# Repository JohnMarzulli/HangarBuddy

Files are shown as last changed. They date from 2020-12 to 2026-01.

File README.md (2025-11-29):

# HangarBuddy

This code controls an AC/DC relay attached to a Raspberry Pi
with a heater plugged in.

It is designed to have a radio of some sort attached that recieves commands and sends responses or alerts.

## Features

1. Extensibility
1. Hangar environment monitoring
1. Continuous vaporized gas monitoring and alerting
1. Status display
1. Rich text commands and responses

## Acknowledgements

This project started as a fork of piWarmer by Maria DeGrazia.
[https://github.com/mdegrazia/piWarmer](https://github.com/mdegrazia/piWarmer)

I want to extend my many thanks to Maria for starting such an amazing project!

The light sensor code is derived from Ada Fruit's samples.
The temperature code is heavily based on the SunFounder sample code.
The ANALOG gas sensor code is also derived from SunFounder sample code.

## Disclaimer

**HangarBuddy is to be used at your own risk.** It is an
experimental device.

## Commands

The commands are not case sensitive.

| SMS Message | Action |
|---|---|
| ON | Turn the Relay/Heater on |
| OFF | Turn the Relay/Heater off |
| STATUS | Return status of the Relay/Heater (on or off) |
| HELP | Return the list of commands. |
| SHUTDOWN | Shutdown the Pi |

## Setup

You will need to modify the HangarBuddy.config file to match your installation.
This file includes a list of phone numbers that are authorized to issue
commands. The file also includes a phone number that any alerts will be sent to.

The basic install process (from scratch):

- Image a micro-SD card using the Raspberry Pi Imager. Keep the user name as `Pi`. You may optionally setup your wifi network name and password.
- In the Pi user directory, make a directory name `src`, navigate into it, then clone the Hangar Buddy repo
- In `/home/user/pi/src/HangarBuddy`, you will need to run and activate a "Python Virtual Environment"
- `python -m venv venv`
- `source ./venv/bin/activate`
- `pip install meshtastic`
- IF you are using an older version of Raspberry Pi OS and NOT using a PI 5: `pip install RPi.GPIO`
- For Pi5 & Bookworm: ``
- `pip install smbus`
- `pip install pyserial`

You will also need to enable some system settings:

- `sudo raspi-config`
- Enable I2C, SPI, 1 Wire Serial, and the Serial interface

## Wiring

**Note**: There are two pin numbering conventions for the Raspberry Pi: Pi numbering and board numbering.

For instance GPIO25 is also known as physical pin 22. It is located on the edge of the PCB, in the middle of the column.

[Raspberry Pi Pin Reference](https://learn.sparkfun.com/tutorials/raspberry-gpio/gpio-pinout)
[Another Pi Pin Reference](https://forum.arduino.cc/t/raspberry-pi-gpio-pins/518283)

### Full Wiring Diagram

Physical Pins 1 and 2 are at the edge of the board with the Micro-SD Card

| Device Connection | Device Connection | Device Connection | Physical Pin / Pi Pin Name | Physical Pin / Pi Pin Name | Device Connection |
|---|---|---|---|---|---|
| | TSL2561 VCC (white)  | | Pin 1 — 3V3 Power | Pin 2 — 5V Power | Display VCC (red) |
| | TSL2561 SDA (green)  | Display SDA (green)  | Pin 3 — GPIO2 / SDA1 | Pin 4 — 5V Power | |
| | TSL2561 SCL (yellow) | Display SCL (yellow) | Pin 5 — GPIO3 / SCL1 | Pin 6 — GND | Display Ground (black) |
| | | DHT22 OUT (gray) | Pin 7 — GPIO4 | Pin 8 — GPIO14 / UART TX | |
| | TSL2561 GND (black)  | | Pin 9 — GND | Pin 10 — GPIO15 / UART RX  | |
| | | | Pin 11 — GPIO17 | Pin 12 — GPIO18 | |
| | | | Pin 13 — GPIO27 | Pin 14 — GND | |
| | | | Pin 15 — GPIO22 | Pin 16 — GPIO23 | |
| MQ2 VCC (white) | | DHT22 VCC (white) | Pin 17 — 3V3 Power | Pin 18 — GPIO24 | |
| | | | Pin 19 — GPIO10 / SPI MOSI | Pin 20 — GND | Relay GND (black) |
| | | | Pin 21 — GPIO9 / SPI MISO  | Pin 22 — GPIO25 | Relay + (blue) |
| | | | Pin 23 — GPIO11 / SPI SCLK | Pin 24 — GPIO8 / SPI CE0 | |
| | | DHT22 GND (black) | Pin 25 — GND | Pin 26 — GPIO7 / SPI CE1 | |
| | | | Pin 27 — ID_SD | Pin 28 — ID_SC | |
| | | | Pin 29 — GPIO5 | Pin 30 — GND | |
| | | | Pin 31 — GPIO6 | Pin 32 — GPIO12 | |
| | | | Pin 33 — GPIO13 | Pin 34 — GND | |
| | | | Pin 35 — GPIO19 | Pin 36 — GPIO16 | |
| MQ2 DO (gray) | | | Pin 37 — GPIO26 | Pin 38 — GPIO20 | |
| MQ2 GND (black) | | | Pin 39 — GND | Pin 40 — GPIO21 | |

Physical pins 39 and 40 are next to the ethernet or USB housing (model dependant)

### Relay

| Wire Color | RPi Pin | Relay Pin |
|---|---|---|
| Red | GPIO25/22 | "+" |
| Black | GND | "-" |

#### Meshtastic & Meshcore Devices

**NOTE** : Make sure the antenna is attached before powering on.
**NOTE** : The Raspberry Pi 4C seems VERY picky about the USB cable used to connect a Heltec device. Try multiple cables.

| Wire Color | RPi Pin | Relay Pin |
|---|---|---|
| Black | USB-A | USB-C |

### MQ-2 Gas Sensor

The labels for the board are hard to read. The Digital output pin is next to the VCC pin. All three pins will be in a row.

| Wire Color | RPi Pin | MQ2 Pin |
|---|---|---|
| white | 3V | Vcc |
| Black | GND | GND |
| Gray | GP26 / 31 | DO |

### Temp Sensor

Note that the temperature sensor probably was delivered with a pig-tail harness.

| Wire Color | RPi Pin | DS18B20 Pin |
|---|---|---|
| Black | GND | GND |
| Red | +5V | VCC |
| Yellow | GPIO 04 / 7 | IN |

## Light Sensor

**NOTE**: If you have the IO hat installed on the Pi, then you
can use the duplicate SDA/SLC connectors on the set screw
side **AND** the connector pin side.

| Wire Color | RPi Pin | TSL2591 Pin |
|---|---|---|
| Red | +3VC | VCC |
| Black | GND | GND |
| White | SDA/03  | SDA |
| Gray | SLC/05  | SLC |

### Status Display

#### Additional Work

You may need to make to "Y" pig tails to support the additional
i2c device. These would split the SDAI and SCLI lines.

**NOTE**: If you do not intend on using both the light sensor AND the display, then you will not not to make pigtails.

| Wire Color | RPi Pin | SF1602 Pin |
|---|---|---|
| Red | +5V | VCC |
| Black | GND | GND |
| White | SDA/GPIO2/Phys 3 | SDA |
| Gray | SCL/GPIO3/Phys 5 | SCL |

## Additional Links And Setup Notes

### Enable Analog-To-Digital Converter For The MQ-2 Gas Sensor

To do this, you need to enable I2C and 1-Wire using `raspi-config`

```bash
sudo raspi-config
```

- Select Option 5 `Interfacing Options`

- Select Option `P5 I2C` and enable
- Select Option `P7 1-Wire` and enable
- Save changes, exit `raspi-config` and reboot your Raspberry Pi

#### Enable the temperature sensor

Modprobe two modules for the temperature sensor:

```bash
sudo modprobe w1-gpio
sudo modprobe w1-therm
```

## Pairing Meshcore

You will want two meshcore devices.

I suggest using the following 3D printed cases: [Heltec V4 Case](https://www.printables.com/model/1460642-3d-printed-enclosure-for-heltec-v4gps)

The first will be a "Companion USB" that will attach to the Hangar Buddy.

The second will probably be a "Companion Bluetooth" that will be conncted to your phone.

The flasher can be obtained at [flasher.meshcore.co.uk](https://flasher.meshcore.co.uk/)

Make sure both devices are running the same version number of the Meshcore firmware.

You will need to pair the two devices using "adverts". Exact instructions can be found on the Meshcore site.

1. Use [Meshcore App](https://meshcore.liamcottle.net/) to:
    1. Name the device
    1. Set region and bandwidth
    1. Send an advert from the device that will be used for the Hangar Buddy.
1. Use the Mesh Core app on your phone to:
    1. Connect by Bluetooth
    2. Name the device
    3. Send back an advert.
1. Use the Web App to send a direct message from the Hangar Buddy device to your phone paired device.

If you are unable to send messages between the devices, consult the Meshcore documentation, Reddit, or others.

## Materials List

All the parts listed are from Amazon

### Absolutely Required

This assumes you are building "from scratch" and need to buy a Raspberry Pi and
associate parts. I have picked a version of the Pi Zero that has Wireless, which
is good if you want to pull the code down directly onto the Pi

Any version of the Raspberry Pi should work for this project as long as it has
GPIO pins, and an I2C bus.

The LiPo battery is absolutely required and used directly by the GSM board.

A MicroUSB to USB adapter is required for the modem to connect into the Pi
Zero's ****only**** USB port.

- [ ] [Raspberry Pi W, case, and IO pins](https://www.amazon.com/Raspberry-Starter-Power-Supply-Premium/dp/B0748MBFTS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)
- [ ] [Adafruit GSM board, SMA edition](https://www.amazon.com/gp/product/B011P07916/ref=oh_aui_detailpage_o02_s00?ie=UTF8&psc=1)
- [ ] [Adafruit 1S Lipo W/ JST connector](https://www.amazon.com/Battery-Packs-Lithium-Polymer-1200mAh/dp/B00J2QET64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)
- [ ] [MicroUSB to USB adapter](https://www.amazon.com/Ksmile%C2%AE-Female-Adapter-SamSung-tablets/dp/B01C6032G0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)
- [ ] [USB to TTL/Serial adapter](https://www.amazon.com/gp/product/B00QT7LQ88/ref=oh_aui_detailpage_o01_s00?ie=UTF8&psc=1)
- [ ] [Ting GSM Sim Card](https://www.amazon.com/gp/product/B013LKL5IQ/ref=oh_aui_detailpage_o02_s00?ie=UTF8&psc=1)
- [ ] [Iot Power Relay](https://www.amazon.com/gp/product/B00WV7GMA2/ref=oh_aui_detailpage_o01_s01?ie=UTF8&psc=1)
- [ ] [Experimentation board with wires](https://www.amazon.com/gp/product/B01LYN4J3B/ref=oh_aui_detailpage_o08_s00?ie=UTF8&psc=1)

#### Antenna

You will need an antenna, and two options have been tried. One is a small
antenna that will work if the device is near a window or your hangar has good
reception. The 7dbi (high gain) antenna option should be used if reception is an
issue

- [ ] [Adafruit GSM Quadband Antenna](https://www.amazon.com/gp/product/B00N4Y2C4G/ref=oh_aui_detailpage_o08_s00?ie=UTF8&psc=1)
- [ ] [High gain antenna](https://www.amazon.com/gp/product/B01M9F08JR/ref=oh_aui_detailpage_o00_s01?ie=UTF8&psc=1)
- [ ] [Case for Sim800C](https://www.thingiverse.com/thing:5012982)

### For Optional Gas Sensor

- [ ] [Additional wires for breadboard](https://www.amazon.com/gp/product/B072L1XMJR/ref=oh_aui_detailpage_o05_s00?ie=UTF8&psc=1)
- [ ] [SunFounder MQ-2 sensor](https://www.amazon.com/gp/product/B013G8A76E/ref=oh_aui_detailpage_o01_s00?ie=UTF8&psc=1)
- [ ] [SunFounder Analog To Digital Converter](https://www.amazon.com/gp/product/B072J2VCMH/ref=oh_aui_detailpage_o05_s01?ie=UTF8&psc=1)

### For Optional Temperature Sensor

- [ ] [SunFounder Temperature Sensor](https://www.amazon.com/gp/product/B013GB27HS/ref=oh_aui_detailpage_o00_s00?ie=UTF8&psc=1)

### For Optional Light Sensor

- [ ] [Adafruit Light Sensor](https://www.amazon.com/gp/product/B00XW2OFWW/ref=oh_aui_detailpage_o00_s00?ie=UTF8&psc=1)

### For Optional Status Display

- [ ] [SunFounder 1602 LCD](https://www.amazon.com/gp/product/B01E6N19YC/ref=oh_aui_detailpage_o01_s00?ie=UTF8&psc=1)

### Adapters

Depending on the version of Raspberry Pi you are using, you may need an adapter. While not required, it is helpful for setup and trouble shooting to have a monitor.

The Raspberry Pi zero has a mini HDMI port.
The R-Pi 4 and 5 both use micro-HDMI.

## Device Reference

### MQ-2 Sensor

[https://tutorials-raspberrypi.com/configure-and-read-out-the-raspberry-pi-gas-sensor-mq-x/](https://tutorials-raspberrypi.com/configure-and-read-out-the-raspberry-pi-gas-sensor-mq-x/)
[http://www.learningaboutelectronics.com/Articles/MQ-2-smoke-sensor-circuit-with-raspberry-pi.php](http://www.learningaboutelectronics.com/Articles/MQ-2-smoke-sensor-circuit-with-raspberry-pi.php)

### Sunfounder Temp Sensor

[https://www.sunfounder.com/learn/Sensor-Kit-v1-0-for-Raspberry-Pi/lesson-17-ds18b20-temperature-sensor-sensor-kit-v1-0-for-pi.html](https://www.sunfounder.com/learn/Sensor-Kit-v1-0-for-Raspberry-Pi/lesson-17-ds18b20-temperature-sensor-sensor-kit-v1-0-for-pi.html)

## Installation

### OS Image

1. Use Raspberry Pi Imager
1. Choose your device
1. 64bit, Trixie based
1. `hangarbuddy` as custom host name
1. The username  `pi` with password `raspberry` are traditional, but easily guessed
1. Use Wifi for setting up.
1. Enable SSH to help setup and remote in. Use password protection. You do not need "Raspberry Pi Connect"

### First Boot

1. Update (To make sure the raspi-config tool is the latest version)
1. Open a PowerShell or command terminal.
1. `ssh pi@hangarbuddy`
1. Use the password `raspberry`. Accept the fingerprint.
1. `sudo raspi-config`
1. System Options:
    1. Setup wifi if not working yet
    1. boot -> Console Text console
    1. Autologin -> Yes
1. Interface options:
    1. SPI -> Enable
    1. I2C -> Enable
    1. Serial
        1. Allow login: no
        1. Allow serial: yes
    1. TURN OFF 1 wire serial
1. Advanced options:
    1. Expand Filesystem
1. "Finish"
1. `sudo reboot now`
1. Wait for a few minutes, then log back in using the `ssh` command
1. `sudo apt update`
1. `sudo apt upgrade`
1. `sudo apt install swig`
1. `sudo apt install python3-lgpio`
1. `sudo apt install liblgpio-dev`
1. `lsusb` - Check to see if a "Silicon Labs CP210x UART Bridge", "Espressif Systems heltec_wifi_lora_32 v4 (16 MB FLASH, 2 MB PSRAM)", or "QinHeng Electronics CH340" is shown.
1. `python --version`. Should be at least 3.13.5

### Source Code

1. Log in to your rasperry pi as the `pi` user.
1. `mkdir src`
1. `cd src`
1. `git clone https://github.com/JohnMarzulli/HangarBuddy/`
1. `cd HangarBuddy`
1. `python -m venv venv`
1. `source ./venv/bin/activate`
1. `pip install -r requirements.txt`
1. `sudo cp hangar_buddy.logrotate.conf /etc/logrotate.d/`
1. `sudo chown root /etc/logrotate.d/hangar_buddy.logrotate.conf`
1. `sudo cp hangar_buddy.service /etc/systemd/system/`
1. `sudo chown root /etc/systemd/system/hangar_buddy.service`
1. `sudo systemctl enable hangar_buddy.service`
1. `sudo reboot`

Once you reboot, the hangar_buddy service should be started automatically.  You can view any startup errors for the service in `/var/log/syslog`.

Running a Python file as a service: <https://gist.github.com/emxsys/a507f3cad928e66f6410e7ac28e2990f>

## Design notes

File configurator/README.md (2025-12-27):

# HangarBuddy Configurator

Local UI to edit HangarBuddy.config on device.

Run locally (install deps first):

```bash
cd configurator
npm install
npm run dev        # starts vite dev server
# or build
npm run build
npm run preview    # preview built site
# start server to expose API
npm start
```

Server starts on port 3000 by default and exposes:
- `GET /api/config` — returns current HangarBuddy.config
- `POST /api/config` — save config (body: { content: string }) — server writes atomically and creates a timestamped backup

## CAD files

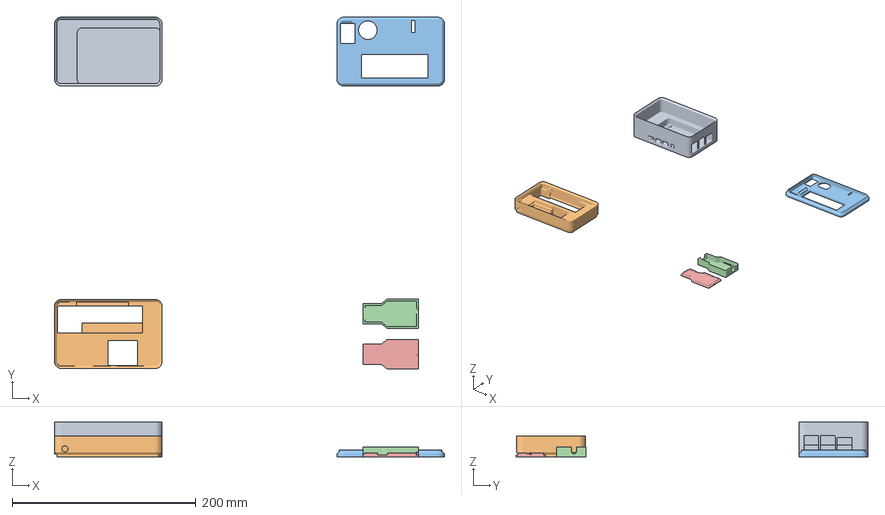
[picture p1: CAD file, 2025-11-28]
case/Case_Assembly.3mf
424.2 x 382.7 x 37.9 mm
Pi Housing.stl
Sensor Carrier.stl
Bezel.stl
body.stl
cover.stl

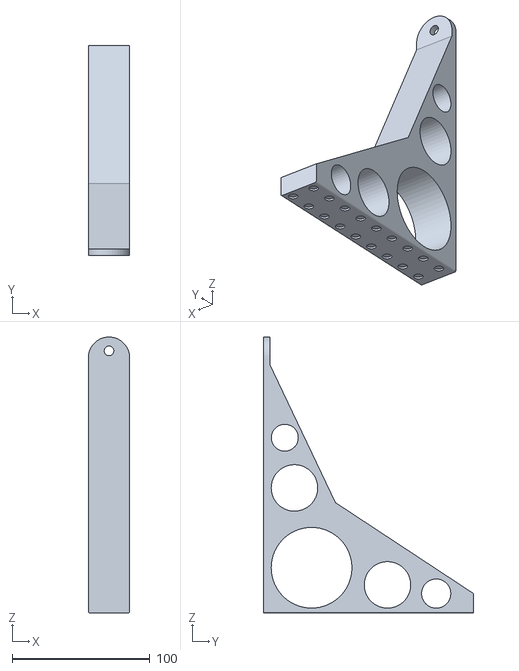
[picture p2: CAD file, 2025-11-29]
case/antenna_bracket.stl
30.0 x 152.0 x 200.0

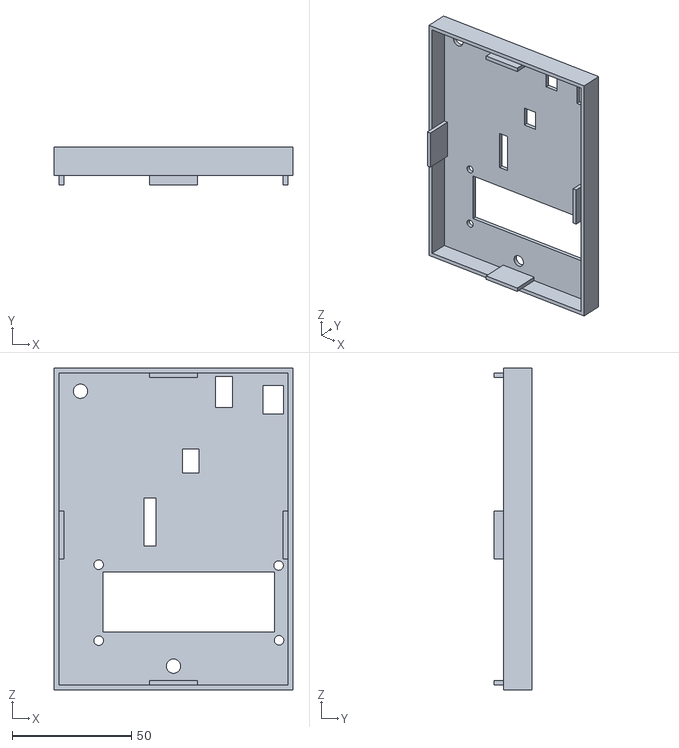
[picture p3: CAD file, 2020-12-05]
media/pi3_case/lid.stl
100.0 x 16.0 x 135.0

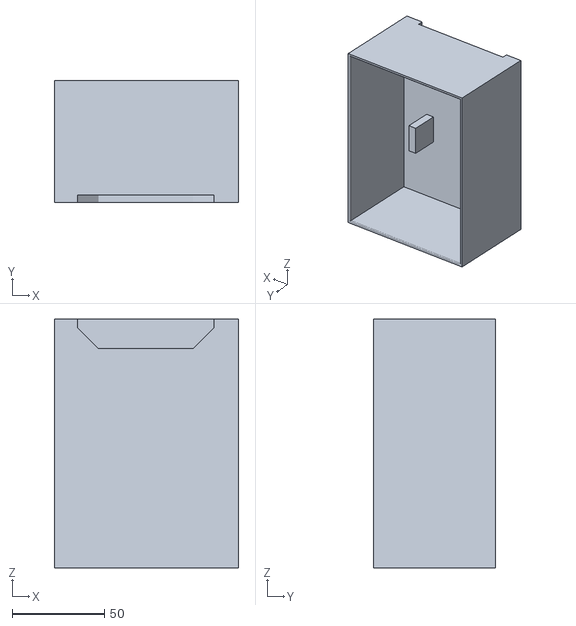
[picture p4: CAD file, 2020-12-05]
media/pi3_case/body.stl
100.0 x 66.0 x 135.0

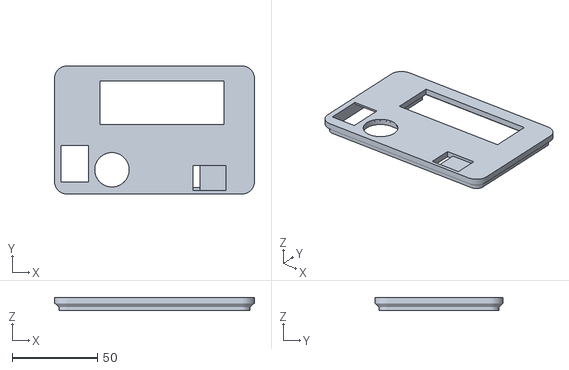
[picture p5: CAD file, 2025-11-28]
case/Bezel.stl
117.0 x 75.0 x 7.66

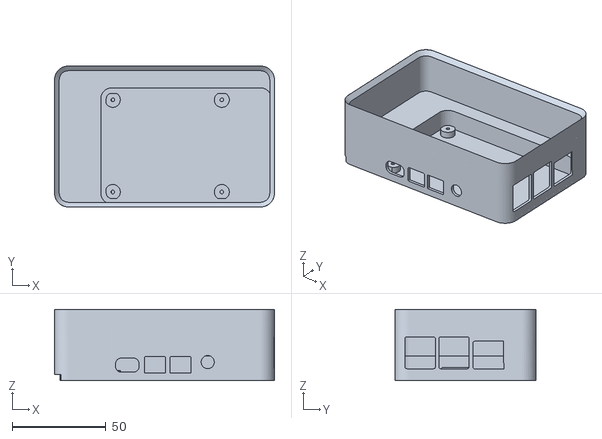
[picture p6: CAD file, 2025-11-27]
case/Pi Housing.stl
117.0 x 75.0 x 37.9

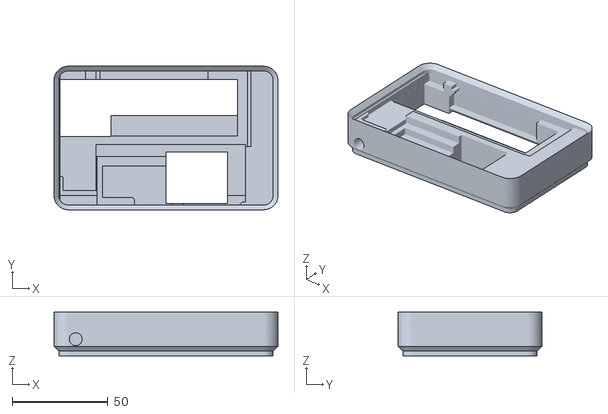
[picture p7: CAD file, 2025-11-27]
case/Sensor Carrier.stl
117.0 x 75.0 x 23.0

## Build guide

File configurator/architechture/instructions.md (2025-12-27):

# Hangar Buddy UI Configurator

## Summary

This is a simple UI that will allow the user to configure their HangarBuddy.

It is intended to be run when the IP address is known, or the Raspberry Pi is in Access Point Mode.

Most users will be using a mobile phone to access this, so mobile and reactive pages are the primary concern.

The UI will be simple, concentrating on configuration values set in `HangarBuddy.config`. Not all values will be configurable.

## Components

We are going to create a new project inside the `configurator` sub-folder.

This is going to be a Typescript/Vite/Node based project that will run on a Raspberry Pi (Bookworm) running Node 18.

## Visual Style And Resolution

There is an existing `style.css` file from a previous project that will be used as the basis. This is to help keep consistency across my projects.

Mobile and responsive targets are the primary concern. Consider an iPhone 16 Pro Max (430x932) to be the MAXIMUM work area. Consider an iPhone SE (375x667) to be the MINIMUM work area.

### Selections

Drop downs will be preferred for most items since there are a select few valid entries.

### Free Form User Configuration

Some items will need to have user added content. This will be such as device ids or phone numbers. These entries will need to have the ability to add a row, remove a row, or edit the value inside. All of them will require at least a single entry.

## Editable Configuration And Other Controls

These are the values that we will want to edit. Each item shuld have a tool tip and brief description.

### Device Type

Valid selections from a Select element (dropdown) are:

- MeshCore
- Meshtastic
- Sim800C
- Test

### UTC Offset

This will be a number selector. Valid options will be from -23 to 23. Options will be in half steps (0.5).

The interface will offer the user to type in a number, or to us UP/DOWN arrows.

When the user leaves the text box, the values will be normalized into the acceptable range.

### Oldest Message To Process

This is a value given in whole minutes.

It will be chosen from a dropdown / Select element.

Options are: 1, 5, 10, 15, 30, 45, 60

### Max Heater Time

This is a value given in whole minutes.

It will be chosen from a dropdown / Select element.

Options are: 15, 30, 60, 90, 120, 150, 180

### Heater Pin

This is a value set as an integer. It will refer to physical board pin.

It will be chosen from a dropdown / Select element.

Options are:

- 11/GPIO 17
- 13/GPIO 27
- 15/GPIO22
- 19/GPIO10
- 21/GPIO9
- 23/GPIO11
- 29/GPIO5
- 31/GPIO6
- 33/GPIO13
- 35/GPIO19
- 37/GPIO26
- 10/GPIO15
- 12/GPIO18
- 16/GPIO23
- 18/GPIO24
- 22/GPIO25
- 24/GPIO8
- 26/GPIO7
- 32/GPIO12
- 36/GPIO16
- 38/GPIO20
- 40/GPIO21

### MQ2

This is an enabled/off selector.

### Temperature Probe

This is an enabled/off selector.

### Light Sensor

This is an enabled/off selector.

If the light sensor is enabled, then three more settings become availble:

- HANGAR_DARK
  - Defaults to 20
  - Minimum is 0
  - Maximum is HANGAR_DIM
- HANGAR_DIM
  - Defaults to 60
  - Minumum is HANGAR_DIM
  - Maximum is HANGAR_LIT
- HANGAR_LIT
  - defaults to 90
  - Minimum is HANGAR_DIM
  - Maximum is 200

These values are whole number entries. Sliders or UP/DOWN arrows may be used.

### Display Enabled

This is an enabled/off selector.

### Test Mode

This is an enabled/off selector.

### Save

This will save any changes that the user has made. Changes are not automatically saved.

When the user elects to save changes, the user should be given an overview of the changes made and an offer to confirm or cancel the save operation.

### Reboot

This will reboot the HangarBuddy. If there are unsaved changes, it will alert the user and give the option to cancel.

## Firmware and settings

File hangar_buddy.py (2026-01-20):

#!/usr/bin/python

"""
Main entry code for HangarBuddy
"""


# Make sure you run:
# `source /home/pi/src/HangarBuddy/venv/bin/activate`
# before attempting to install packages or run.

#
#
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
# You can view the GNU General Public License at <http://www.gnu.org/licenses/>
#
# Written for Python 3.x
# You will need to "pip3 install meshtastic"
#
# Includes provisions for the basic logic to be run
# for development\testing under Windows or Mac
#
# NOTE: To have this start automatically
#
# 1. sudo vim /etc/rc.local
# 2. Add the following line:
#    cd /home/pi/HangarBuddy
# 3. (OPTIONAL) To have the device update its code automatically
#    when connected to wifi, add the following line
#    at the bottom of the file:
#    /bin/sh /home/pi/HangarBuddy/update.sh
# 4. Add the following line at the bottom of the file:
#    NOTE: if this should be below the optional auto-update line
#    python /home/pi/HangarBuddy/hangar_buddy.py &

import sys
from datetime import datetime, timedelta, timezone
from time import sleep

import configuration
from command_processor.command_processor import CommandProcessor
from communication.meshcore_serial import MeshcoreSerial
from communication.meshtastic_serial import MeshtasticSerial
from communication.message_send_request import MessageSendRequest
from communication.received_message import ReceivedMessage
from communication.sim800c_serial import Sim800cSerial
from communication.test_message_device import TestMessagingDevice
from devices.displays.sf_1602_lcd import Sf1602Display
from devices.interfaces.display_device import DisplayDevice
from devices.interfaces.messaging_device import MessagingDevice
from devices.mocks.console_display import ConsoleDisplay
from display.display_manager import DisplayManager
from display.display_message import DisplayMessage
from display.priority import Priority
from lib import local_debug
from lib.system_level_logging import SystemLevelLogger
from lib.time_correction import TIME_CORRECTION
from managers.gas_safety_manager import GasSafetyManager
from managers.light_manager import LightManager
from managers.relay_manager import RelayManager
from managers.sensors_manager import SensorsManager

CONFIGURATION = configuration.Configuration()

DISPLAY_MANAGER: DisplayManager = DisplayManager(ConsoleDisplay() if local_debug.is_debug() else Sf1602Display())

HANGAR_BUDDY_LOGGER: SystemLevelLogger = SystemLevelLogger(CONFIGURATION, "HangarBuddy")
MESSAGE_LOGGER: SystemLevelLogger = SystemLevelLogger(CONFIGURATION, "Messages")
MESSAGING_DEVICE_LOGGER: SystemLevelLogger = SystemLevelLogger(
    CONFIGURATION,
    "MessagingDevice",
)
RELAY_LOGGER: SystemLevelLogger = SystemLevelLogger(CONFIGURATION, "Relay")
SENSORS_LOGGER: SystemLevelLogger = SystemLevelLogger(CONFIGURATION, "Sensors")
SENSORS_MANAGER = SensorsManager(CONFIGURATION, SENSORS_LOGGER)
MESSAGE_HISTORY: list[ReceivedMessage] = []


def __get_messaging_device__(
    config: configuration.Configuration,
) -> MessagingDevice:
    if config.device_type.lower() == "meshtastic":
        MESSAGING_DEVICE_LOGGER.info("Using Meshtastic messaging device")

        return MeshtasticSerial(MESSAGING_DEVICE_LOGGER)
    elif config.device_type.lower() == "meshcore":
        MESSAGING_DEVICE_LOGGER.info("Using Meshcore messaging device")

        return MeshcoreSerial(MESSAGING_DEVICE_LOGGER)
    elif config.device_type.lower() == "sim800c":
        MESSAGING_DEVICE_LOGGER.info("Using SIM800C messaging device")

        return Sim800cSerial(MESSAGING_DEVICE_LOGGER)
    elif config.device_type.lower() == "test":
        MESSAGING_DEVICE_LOGGER.info("Using Loopback/Test messaging device")

        return TestMessagingDevice(MESSAGING_DEVICE_LOGGER)

    raise RuntimeError(f"Unknown device type: {config.device_type}")


MESSAGING: MessagingDevice = __get_messaging_device__(CONFIGURATION)


def __get_time_text__() -> str:
    time = TIME_CORRECTION.get_time()
    return f"{time:%Y-%m-%d %H:%M:%S}UTC"


def log_message_sent(recipient: str, message: str):
    lines = message.split("\n")

    log_message: str = "SENDING\n"
    log_message += f"    TO: {recipient}\n"
    log_message += f"    AT: {__get_time_text__()}\n"
    log_message += "    ```\n"
    for line in lines:
        log_message += f"    {line.strip()}\n"
    log_message += "    ```"

    MESSAGE_LOGGER.info(log_message)


def log_message_received(message: ReceivedMessage):
    lines = message.text.split("\n")

    log_message: str = "RECEIVED\n"
    log_message += f"    FROM: {message.sender}\n"
    log_message += f"    AT: {__get_time_text__()}\n"
    log_message += "    ```\n"
    for line in lines:
        log_message += f"    {line.strip()}\n"
    log_message += "    ```"

    MESSAGE_LOGGER.info(log_message)


def send_mesage(recipient: str, message: str) -> bool:
    """
    Sends an alert message.
    """

    log_message_sent(recipient, message)

    # Here you can add more logic to send the alert, e.g., via email or SMS.
    # For now, it just logs the message.
    try:
        MESSAGING.send(MessageSendRequest(recipient, message))

        return True
    except Exception as ex:
        HANGAR_BUDDY_LOGGER.error(f"Error sending message to {recipient}, EX={ex}")

        return False


def send_message_to_all(message: str) -> bool:
    """
    Sends an alert message.
    """

    DISPLAY_MANAGER.show(
        DisplayMessage(
            message,
            priority=Priority.HIGH,
            ttl=timedelta(seconds=60),
            min_display_time=timedelta(seconds=15),
        )
    )

    is_one_message_sent: bool = False

    for recipient in CONFIGURATION.allowed_senders:
        is_sent: bool = send_mesage(recipient, message)
        is_one_message_sent = is_one_message_sent or is_sent

    if not is_one_message_sent:
        HANGAR_BUDDY_LOGGER.error("ERROR trying to send message to any authorized receivers")

    return is_one_message_sent


def is_for_this_node(recipient: str) -> bool:
    message_to = recipient.strip()

    return message_to == MESSAGING.device_id


def is_from_known_sender(sender: str) -> bool:
    return sender in CONFIGURATION.allowed_senders


def get_message_text(message: dict) -> str:
    try:
        return message["decoded"]["payload"].decode("utf-8")
    except Exception:
        HANGAR_BUDDY_LOGGER.error("Error decoding message payload")

        return ""


def __get_ascii_only__(text: str) -> str:
    return "".join(char for char in text if char.isascii())


def process_messages(command_processor: CommandProcessor, display_manager: DisplayManager):
    messages = MESSAGING.get_incoming_messages()

    for message in messages:
        if not is_for_this_node(message.recipient):
            continue

        if not is_from_known_sender(message.sender):
            send_mesage(message.sender, "BLOCKED")

            display_manager.show(
                DisplayMessage(
                    f"UNAUTH MSG FROM:\n{__get_ascii_only__(message.sender)}",
                    priority=Priority.HIGH,
                    ttl=timedelta(seconds=60),
                    min_display_time=timedelta(seconds=15),
                )
            )

            known_senders_text: str = ",".join(CONFIGURATION.allowed_senders)
            unknown_sender_message: str = f"Unknown sender `{message.sender}`, known: {known_senders_text}"

            send_message_to_all(unknown_sender_message)

            continue

        display_manager.show(
            DisplayMessage(
                f"{__get_ascii_only__(message.sender)}\n{__get_ascii_only__(message.text)}",
                priority=Priority.HIGH,
                ttl=timedelta(seconds=60),
                min_display_time=timedelta(seconds=15),
            )
        )

        MESSAGE_HISTORY.append(message)
        log_message_received(message)
        response = command_processor.process(message.text, MESSAGE_HISTORY)

        if response is not None and len(response) > 0:
            send_message_to_all(response)
            HANGAR_BUDDY_LOGGER.info(f"Response sent: {response}")


def prevent_pc_from_sleeping():
    if sys.platform == "win32":
        import ctypes

        ES_CONTINUOUS = 0x80000000
        ES_SYSTEM_REQUIRED = 0x00000001
        ctypes.windll.kernel32.SetThreadExecutionState(ES_CONTINUOUS | ES_SYSTEM_REQUIRED)


def __update_display__(
    display_manager: DisplayManager,
    command_processor: CommandProcessor,
):
    status: list[str] = command_processor.get_short_status_text()
    display_text = f"{status[0]}\n{status[1]}"
    info_request: DisplayMessage = DisplayMessage(
        display_text,
        priority=Priority.LOW,
        ttl=timedelta(seconds=5),
        min_display_time=timedelta(seconds=0.5),
    )

    display_manager.show(info_request)


# TODO: See if there is a way to improve the accuracy of the temp sensor
# TODO: Command to return hop count & route


async def __connect_messaging_device__() -> bool:
    # This is intentionally not using the time correction system
    # since it is only used for relative timekeeping
    # and not anything user facing
    start_time = datetime.now(timezone.utc)
    end_time = start_time + timedelta(minutes=5)

    while datetime.now(timezone.utc) < end_time:
        if MESSAGING.__is_connected__():
            return True

        sleep(5)
        HANGAR_BUDDY_LOGGER.info("Connecting to device...")
        await MESSAGING.service()

    return False


async def main():
    prevent_pc_from_sleeping()

    DISPLAY_MANAGER.show_now("Starting...")

    is_connected: bool = await __connect_messaging_device__()

    if not is_connected:
        HANGAR_BUDDY_LOGGER.error("Unable to connect to messaging device")
        DISPLAY_MANAGER.show_now("ERROR:\nNo Msg Device")

        return

    heater = RelayManager(CONFIGURATION, RELAY_LOGGER, send_message_to_all)
    light_manager: LightManager = LightManager("Hangar", SENSORS_MANAGER, send_message_to_all)
    gas_safety_manager: GasSafetyManager = GasSafetyManager(SENSORS_MANAGER, heater, send_message_to_all)
    command_processor = CommandProcessor(SENSORS_MANAGER, heater, gas_safety_manager)

    DISPLAY_MANAGER.show_now("Initializing...")

    HANGAR_BUDDY_LOGGER.info("Starting HangarBuddy...")
    HANGAR_BUDDY_LOGGER.info(f"IP:{local_debug.get_ip_address()}")

    send_message_to_all("Starting HangarBuddy...")
    send_message_to_all(command_processor.get_full_status_text())

    HANGAR_BUDDY_LOGGER.info(f"Connected to {MESSAGING.device_name}/{MESSAGING.device_id}")

    while True:
        SENSORS_MANAGER.update()
        await MESSAGING.service()
        light_manager.update()
        gas_safety_manager.update()
        heater.update()
        process_messages(command_processor, DISPLAY_MANAGER)
        __update_display__(DISPLAY_MANAGER, command_processor)
        DISPLAY_MANAGER.update()

        sleep(0.5)


if __name__ == "__main__":
    import asyncio

    asyncio.run(main())

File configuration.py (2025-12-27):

"""Module to abstract and hide configuration."""

# encoding: UTF-8

import os.path

from configparser import ConfigParser

import lib.local_debug as local_debug

# read in configuration settings


def get_config_file_location():
    """
    Get the location of the configuration file.

    >>> get_config_file_location()
    './HangarBuddy.config'
    """

    paths = ["./HangarBuddy.config", "../HangarBuddy.config", "../../HangarBuddy.config"]

    for path in paths:
        if os.path.exists(path):
            return path

    raise RuntimeError("Unable to find configuration file")


class Configuration(object):
    """
    Object to handle configuration of the HangarBuddy.
    """

    def get_log_directory(self):
        """returns the location of the logfile to use."""

        return self.__config_parser__.get("SETTINGS", "LOGFILE_DIRECTORY")

    def __init__(self):
        file_path = get_config_file_location()
        print(f"SETTINGS:{file_path}")

        self.__config_parser__: ConfigParser = ConfigParser()
        self.__config_parser__.read(file_path, encoding="utf-8")

        self.device_type: str = self.__config_parser__.get("SETTINGS", "DEVICE_TYPE")
        self.relay_pin: int = self.__config_parser__.getint("SETTINGS", "HEATER_PIN")
        self.is_mq2_enabled: bool = self.__config_parser__.getboolean("SETTINGS", "MQ2")
        self.is_temp_probe_enabled: bool = self.__config_parser__.getboolean("SETTINGS", "TEMP")
        self.is_light_sensor_enabled: bool = self.__config_parser__.getboolean("SETTINGS", "LIGHT_SENSOR")
        self.hangar_dark: int = self.__config_parser__.getint("SETTINGS", "HANGAR_DARK")
        self.hangar_dim: int = self.__config_parser__.getint("SETTINGS", "HANGAR_DIM")
        self.hangar_lit: int = self.__config_parser__.getint("SETTINGS", "HANGAR_LIT")
        raw_senders_entry: str = self.__config_parser__.get("SETTINGS", "ALLOWED_SENDERS")
        raw_senders_list: list[str] = raw_senders_entry.split(",")
        self.allowed_senders: list[str] = [sender.strip() for sender in raw_senders_list if sender.strip()]
        self.max_minutes_to_run: int = self.__config_parser__.getint("SETTINGS", "MAX_HEATER_TIME")
        self.log_filename: str = f"{self.get_log_directory()}hangar_buddy.log"
        self.max_message_age: int = self.__config_parser__.getint("SETTINGS", "OLDEST_MESSAGE_TO_PROCESS")
        self.utc_offset = self.__config_parser__.getint("SETTINGS", "UTC_OFFSET")

##################
### UNIT TESTS ###
##################


def test_configuration():
    """Test that the configuration is valid."""
    config = Configuration()

    assert config.allowed_senders is not None
    assert len(config.allowed_senders) > 0
    assert config.relay_pin is not None
    assert config.relay_pin >= 1
    assert config.relay_pin < 32
    assert config.is_mq2_enabled is not None
    assert config.is_temp_probe_enabled is not None
    assert config.log_filename is not None
    assert config.max_minutes_to_run == 60


if __name__ == "__main__":
    import doctest

    print("Starting tests.")

    doctest.testmod()

    print("Tests finished")

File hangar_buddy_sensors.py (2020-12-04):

"""
Module to abstract and help with keeping our sensors and
configuration in order
"""

import logging
import logging.handlers

from lib.gas_sensor import GasSensor
from lib.light_sensor import LightSensor, LightSensorResult
import lib.temp_probe as temp_probe
from lib.recurring_task import RecurringTask

DEFAULT_SENSOR_LOG = 'sensors.log'
DEFAULT_LIGHT_SENSOR_UPDATE_INTERVAL = 30
DEFAULT_GAS_SENSOR_UPDATE_INTERVAL = 60
DEFAULT_TEMPERATURE_SENSOR_UPDATE_INTEVAL = 120


class Sensors(object):
    """
    Object to handle and help abstract all
    of the sensors we could have or use.
    """

    def __init__(
        self,
        configuration
    ):
        self.__logger__ = logging.getLogger("sensors")
        self.__logger__.setLevel(logging.INFO)
        self.__handler__ = logging.handlers.RotatingFileHandler(
            configuration.get_log_directory() + DEFAULT_SENSOR_LOG,
            maxBytes=1048576,
            backupCount=3)
        self.__handler__.setFormatter(
            logging.Formatter(
                '%(asctime)s %(levelname)-8s %(message)s'))
        self.__logger__.addHandler(self.__handler__)

        self.__gas_sensor__ = None
        self.__light_sensor__ = None

        self.current_gas_sensor_reading = None
        self.current_light_sensor_reading = None
        self.current_temperature_sensor_reading = None

        self.__light_sensor__ = LightSensor()

        if self.__light_sensor__.enabled:
            RecurringTask(
                "__update_light_sensor__",
                DEFAULT_LIGHT_SENSOR_UPDATE_INTERVAL,
                self.__update_light_sensor__,
                self.__logger__)

        if configuration.is_mq2_enabled:
            self.__gas_sensor__ = GasSensor()

            if self.__gas_sensor__ is not None and self.__gas_sensor__.enabled:
                RecurringTask(
                    "__update_gas_sensor__",
                    DEFAULT_GAS_SENSOR_UPDATE_INTERVAL,
                    self.__update_gas_sensor__,
                    self.__logger__)

        if configuration.is_temp_probe_enabled:
            RecurringTask(
                "__update_temperature_sensor__",
                DEFAULT_TEMPERATURE_SENSOR_UPDATE_INTEVAL,
                self.__update_temperature_sensor__,
                self.__logger__)

    def __update_light_sensor__(
        self
    ):
        """
        Reads the light sensor and saves the result.
        """

        self.current_light_sensor_reading = LightSensorResult(
            self.__light_sensor__)
        self.__logger__.info(
            "LIGHT: Lux={}, VIS={}, IR={}".format(
                int(self.current_light_sensor_reading.lux),
                self.current_light_sensor_reading.full_spectrum,
                self.current_light_sensor_reading.infrared))

    def __update_gas_sensor__(
        self
    ):
        """
        Read the gas sensor and keep it up to date.
        """

        if not self.__gas_sensor__.enabled:
            self.current_gas_sensor_reading = None
            return

        self.current_gas_sensor_reading = self.__gas_sensor__.update()

        if self.current_gas_sensor_reading is not None:
            self.__logger__.info(
                "GAS: Level={}, Detected={}".format(
                    self.current_gas_sensor_reading.current_value,
                    self.current_gas_sensor_reading.is_gas_detected))

    def __update_temperature_sensor__(
        self
    ):
        """
        Reads the temperature senso and keep the results.
        """

        sensor_readings = temp_probe.read_sensors()
        if sensor_readings is not None:
            results_count = len(sensor_readings)
            if results_count > 0:
                self.current_temperature_sensor_reading = int(
                    sensor_readings[0])
                self.__logger__.info(
                    "TEMP: F={}".format(
                        self.current_temperature_sensor_reading))
            else:
                self.current_temperature_sensor_reading = None

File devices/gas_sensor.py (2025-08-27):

from devices.gas_sensor_result import GasSensorResult

DEFAULT_TRIGGER_THRESHOLD: int = 245
DEFAULT_ALL_CLEAR_THRESHOLD: int = 235


class GasSensor(object):
    """
    Class to help with the gas sensor.
    """

    def __init__(
        self,
        sensor_trigger_threshold: int = DEFAULT_TRIGGER_THRESHOLD,
        sensor_all_clear_threshold: int = DEFAULT_ALL_CLEAR_THRESHOLD,
    ):
        self.current_value: int | None = DEFAULT_ALL_CLEAR_THRESHOLD
        self.sensor_trigger_threshold: int = sensor_trigger_threshold
        self.sensor_all_clear_threshold: int = sensor_all_clear_threshold
        self.enabled: bool = False
        self.is_gas_detected: bool = False

    def update(self) -> GasSensorResult:
        return GasSensorResult(False, 0)

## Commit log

2018-03-18 Fix issue with Recurring Task "leaking" dead threads.
2018-11-11 Fixes issue where a number of threads could get spawned and become orphaned.
2020-11-30 Update GPIO pin out to include physical number
2020-11-30 Make sure flow control is enabled.
2020-12-02 Show a temperature during self-test
2020-12-02 More diagnostics for the temperature probe.
2020-12-02 Add sensor id to diagnostics.
2020-12-02 Better config directions for the temp probe.
2020-12-04 Update docs on wiring.
2020-12-04 Add full sensors check.
2020-12-04 Simplifiy some threaded tasks to be time-sliced instead.
2020-12-05 Deal with pathing issues during crontab startup
    [configuration.py]
2020-12-05 Add files for an integrated case.
    [body.stl, lid.stl]
2025-08-18 Make sure the sensors are serviced outside of the message loop
2025-08-18 Filter out messages not intended for the device.
2025-08-27 Use correct form of join
    [hangar_buddy.py]
2025-08-27 Use the term "RELAY"
2025-08-27 Make sure the heater relay is processed.
2025-08-27 Have the command processor handle relay swith messages.
2025-08-27 Defer all message handling and relay management to the managers.
2025-08-27 Refine sensor logging
2025-08-27 Give better relay messages.
2025-08-27 Move gas sensor reading to own file.
2025-08-27 Create a generic way to simulate sensor readings.
2025-08-27 Use a better way to simulate the gas sensor
2025-08-28 Refactor gas sensors
2025-08-28 Refactor light sensors, add result simulator
2025-08-28 Move sensor simulator into Mocks
2025-08-28 Refactor temperature probes.
2025-08-28 Prevent Win31 dev environments from auto-sleeping while testing and debugging.
    [hangar_buddy.py]
2025-09-01 Fix string interpolation issue
    [tsl2591_light_sensor.py]
2025-09-01 Make sure the light sensor can run as a stand alone file
2025-09-01 Get temp sensor running again.
2025-09-01 Update wiring for simpler digital output.
2025-09-01 Support a simpler digital output for the MQ2 gas sensor. Support RPI5
2025-09-02 Updated wiring schematics
2025-09-04 Do not add text for sensors that are not running or collecting
2025-09-04 Update the light sensor more often, log less frequently
2025-09-13 Add interface for generic messaging device.
2025-09-13 Allow for the messaging device to be selected in the configuration
2025-09-13 Keep track of elapsed time properly.
2025-09-13 Add PyDocs and fix typos.
    [ds18b20_temperature_sensor.py, gas_sensor.py, hangar_buddy.py]
2025-09-14 Convert temp probe readings to use TempResult object so F and C are available.
2025-09-20 Debug RPi UTF-8 issue
    [meshcore_serial.py]
2025-11-17 Include instructions on how to pair Meshcore devices
2025-11-25 Add STLs for the Pi enclosure
    [Bezel.stl, Case_Assembly.3mf, Pi Housing.stl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]
2025-11-26 Instructions to make sure the USB device is connected
2025-11-27 Update wiring diagram
2025-11-27 Attempt to support DHT22 temp/humidity sensors
2025-11-27 More wiring diagram improvements
2025-11-27 New bezel and carrier attachment mechanism
    [Bezel.stl, Case_Assembly.3mf, Pi Housing.stl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]
2025-11-28 Updates to bezel
    [Bezel.stl, Case_Assembly.3mf]
2025-11-29 Adjust suggested wiring locations
2025-11-29 Add antenna bracket to source
    [antenna_bracket.stl]
2025-11-29 Fix address of 2561
    [tsl2561_light_sensor.py]
2025-11-29 Fix 2561 read registers
    [tsl2561_light_sensor.py]
2025-11-29 Do not power down 2561
2025-11-29 Never power down 2561
2025-11-29 Remove print calls.
2025-11-29 Send back a "rejected" message to help diagnose authorization issues.
    [hangar_buddy.py]
2025-11-30 Refactor location of displays to fit with driver/mock layout
2025-11-30 Give the loop back device a name
2025-11-30 Skip the `Clear` call since the text is justified.
    [display_device.py]
2026-01-20 Add a new system that uses the timestamps on incoming messages to correct the user facing time.
    [hangar_buddy.py, meshcore_serial.py, meshtastic_serial.py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]
